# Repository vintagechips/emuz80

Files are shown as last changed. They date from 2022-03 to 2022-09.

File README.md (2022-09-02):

# emuz80
The computer with only Z80 and PIC18F47Q43<br>
<br>
The required clock frequency for the Z80 is as follows<br>
emuz80_pic.hex 2.5MHz<br>
emuz80_pic_kuma.hex 2.5MHz<br>
emuz80_pic_hlide.hex 4.6MHz<br>
emuz80_pic_yyhayami.hex 4.3MHz<br>
emuz80_pic_gazelle.hex 6MHz PIC must be replaced with PIC18F47Q84<br>
<br>
Hardware information can be found here. It is written in Japanese.<br>
https://vintagechips.wordpress.com/2022/03/05/emuz80_reference/

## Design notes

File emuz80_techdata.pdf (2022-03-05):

# EMUZ80技術資料

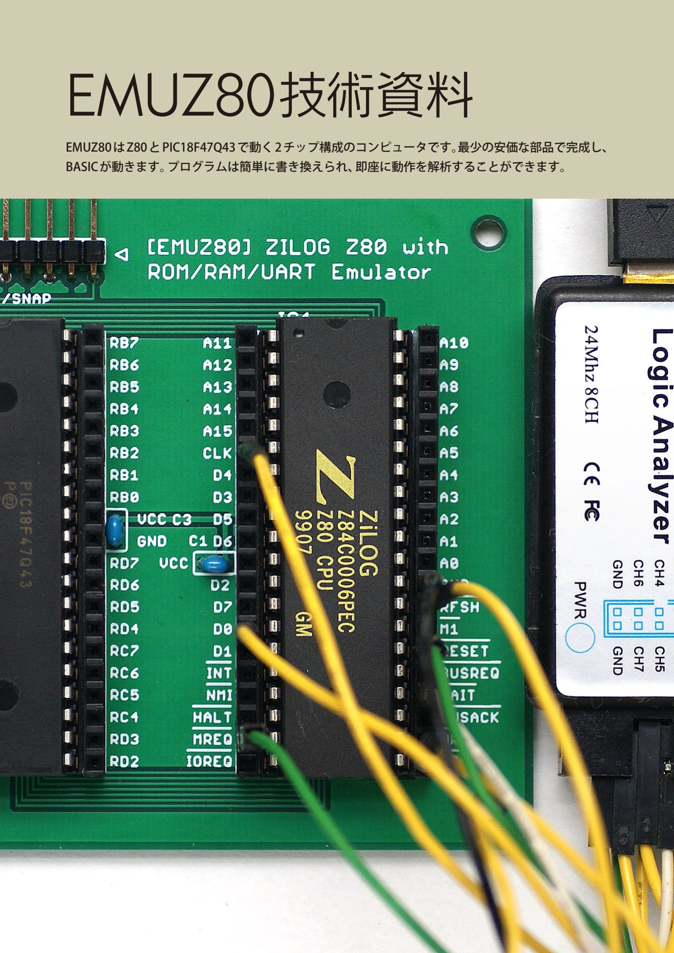
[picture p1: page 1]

EMUZ80 は Z80 と PIC18F47Q43 で動く 2 チップ構成のコンピュータです。最少の安価な部品で完成し、 BASIC が動きます。プログラムは簡単に書き換えられ、即座に動作を解析することができます。

目次

EMUZ80 の概要─3
部品表─4
回路図─5
ソルダバッドの処理─6
AC アダプタ─7
プログラムの書き込み─8
◉書き込みの準備 8
◉標準プログラムの書き込み 9
◉標準プログラムの改編 10
◉独自のプログラムの実験と解析 10
アドレスマップ─11
USB- シリアル変換ケーブル / アダプタ─12
端末ソフトの設定─13
起動の確認─14
別途配布物一覧─15

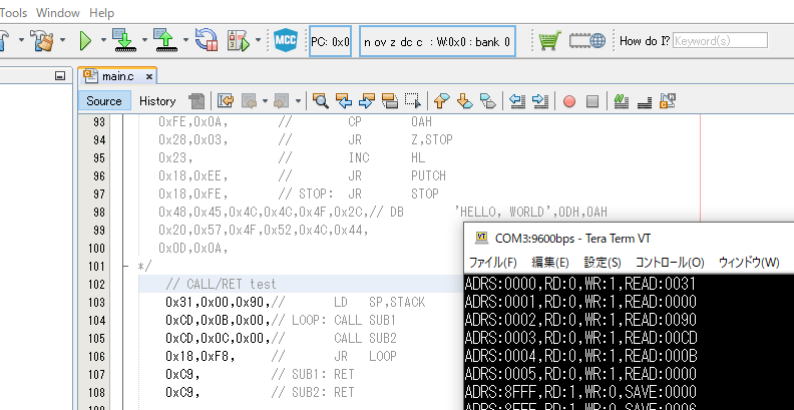
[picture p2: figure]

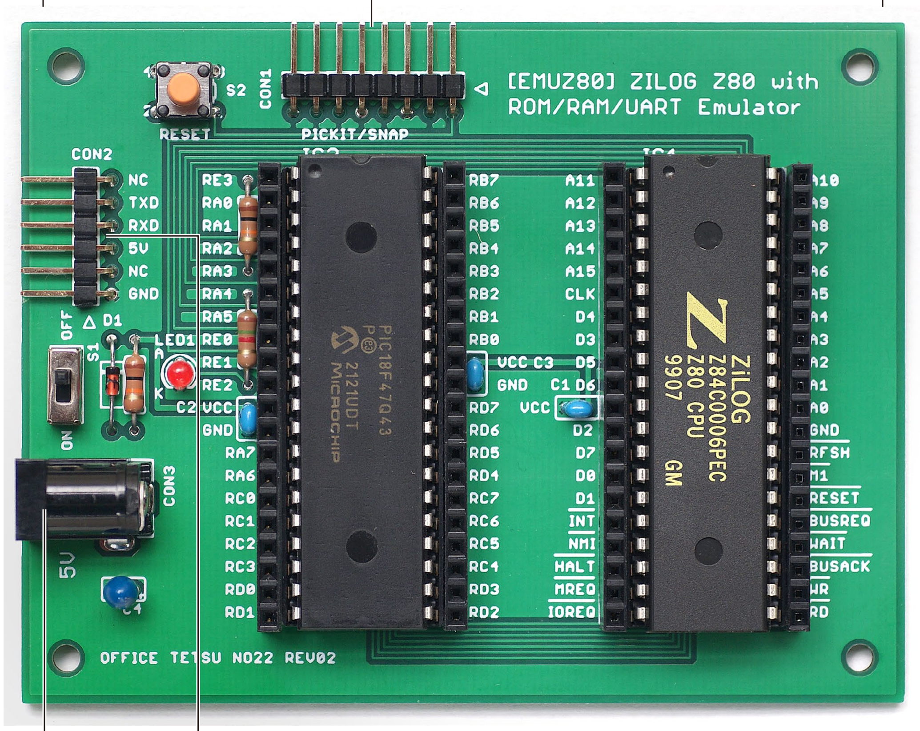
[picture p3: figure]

3

# EMUZ80の概要

EMUZ80 は部品代 1000 円で完成する Z80 のコンピュータです。ROM、RAM、シリアル（UART）は PIC18F47Q43 でエ ミュレートします。標準プログラムだと、Z80 は 2.5MHz/ 最悪 7 ウェイトで動き、BASIC を実行します。標準プログラム はいっそうの高速化を目指して改良する余地があります。ウデに自信のある人はぜひ挑戦してください。

❶本体の部品─部品表にしたがってご自身で揃え、プリント基板の部品番号が一致する位置に取り付けてください。 ❷ Snap 接続端子─ PIC18F47Q43 にプログラムを書き込むとき Snap を取り付けます。
❸ DC ジャック─電圧 5V、電流 500mA 以上、内径 2.1 mm、センタープラスの AC アダプタを接続してください。 ❸シリアル端子─ TTL-232R-5V または同等の USB- シリアル変換ケーブル / アダプタでパソコンと接続してください。
❶本体の部品 | ❷ Snap 接続端子
❸ DC ジャック | ❹シリアル端子

4

部品番号 | 型番 | 数量 | 仕様 | 販売店
IC1 | Z80 CPU | 1 | マイクロプロセッサ | オレンジピコ、若松通商
IC2 | PIC18F47Q43 | 1 | マイクロコントローラ | オレンジピコ、秋月電子通商
D1 | 1N4148 | 1 | 小信号スイッチングダイオード | オレンジピコ、秋月電子通商、若松通商
LED1 | OSRRH23133A | 1 | φ 3mm 一般 LED 各色 | オレンジピコ、秋月電子通商
R1、R2 | 10k Ω（1/4W） | 2 | カーボン抵抗 / 金属皮膜抵抗 | オレンジピコ、秋月電子通商
R3 | 1.5k Ω（1/4W） | 1 | カーボン抵抗［注 1］ | オレンジピコ、秋月電子通商
C1 ～ C3 | 0.1 μ F（50V） | 3 | 積層セラミックコンデンサ | オレンジピコ、秋月電子通商
C4 | 10 μ F（16V） | 1 | 電解 / タンタルコンデンサ | オレンジピコ、秋月電子通商
CON1、CON2 | PH-1x40RG(2) | 1 | 1 列 L 型ピンヘッダ［注 2］ | オレンジピコ、秋月電子通商
CON3 | MJ-179PH | 1 | 2.1mm φ標準 DC ジャック | オレンジピコ、秋月電子通商
S1 | SS-12D00-G5 | 1 | スライドスイッチ | オレンジピコ、秋月電子通商
S2 | DTS-6-V | 1 | 小型タクトスイッチ | オレンジピコ、秋月電子通商
─ | FH-1x20 | 4 | 20 ピン 1 列ピンソケット［注 3］ | オレンジピコ、秋月電子通商
─ | 2227-40-06 | 2 | 40 ピン IC ソケット 600mil | オレンジピコ、秋月電子通商
［注 1］R3 の抵抗値は使用する LED の輝度に応じて調整してください。
［注 2］CON1 は 8 ピン、CON2 は 6 ピンのところで折って使います。
［注 3］ご利用のジャンパー線によってはピンヘッダを取り付けてください。実験や解析をしない場合は不要です。

# 部品表

本体の部品は下に示す部品表にしたがって揃えてください。部品表の部品番号とプリント基板の部品番号を照合し、 所定の位置に取り付けると組み立て完了です。部品表には実験や解析の作業を想定した部品が含まれます。そうした 部品は、ご利用のジャンパー線などに合わせて変更し、あるいは省略することを検討してください。

## ［通販サイト］

秋月電子通商─ http://akizukidenshi.com/
オレンジピコ─ https://store.shopping.yahoo.co.jp/orangepicoshop/若松通商─ http://wakamatsu.co.jp/biz/
※ 2022 年 3 月 15 日時点の情報です。

# 回路図

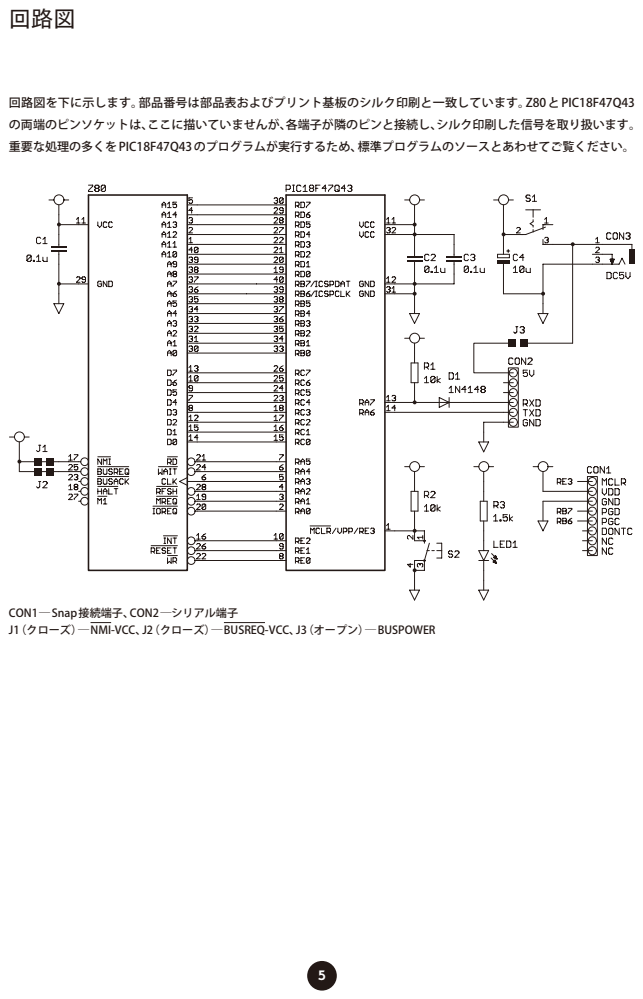
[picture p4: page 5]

回路図を下に示します。部品番号は部品表およびプリント基板のシルク印刷と一致しています。Z80 と PIC18F47Q43
の両端のピンソケットは、ここに描いていませんが、各端子が隣のピンと接続し、シルク印刷した信号を取り扱います。
重要な処理の多くを PIC18F47Q43 のプログラムが実行するため、標準プログラムのソースとあわせてご覧ください。

CON1 ─ Snap 接続端子、CON2 ─シリアル端子
J1（クローズ）─NMI-VCC、J2（クローズ）─BUSREQ-VCC、J3（オープン）─ BUSPOWER

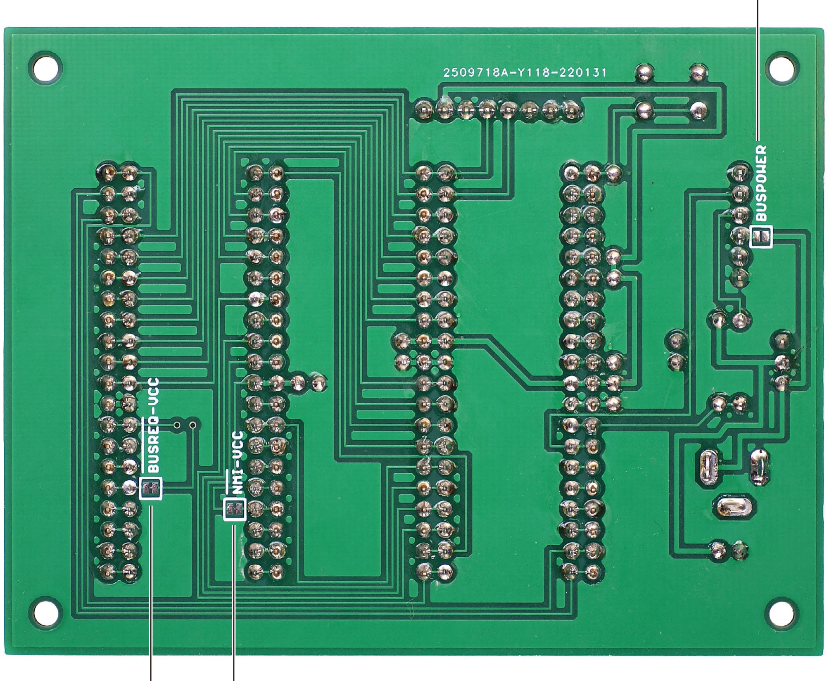
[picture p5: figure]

6

# ソルダバッドの処理

プリント基板のハンダ面に 3 か所のソルダバッドがあります。これらは原則として何もしないでください。J1 と J2 は 不使用端子を無効に固定しています。J3 は電源を USB のバスパワーからとるときクローズしますが、その場合、多く の USB- シリアル変換アダプタは電源スイッチを入れた瞬間にリセットします（TTL-232R-5V は正常に動作します）。

J3（オープン）─ BUSPOWER

J2（クローズ）─BUSREQ-VCC

J1（クローズ）─NMI-VCC

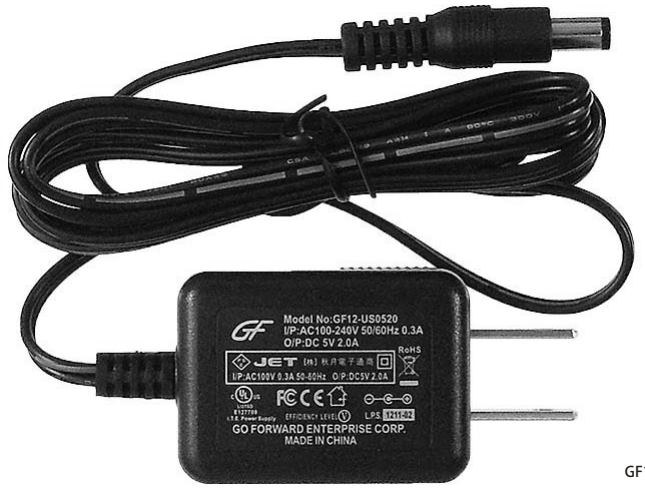
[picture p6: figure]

7

# ACアダプタ

電源は原則として AC アダプタからとります。電圧 5V、電流 500mA 以上、内径 2.1 mm、センタープラスの AC アダプタ を DC ジャックに接続してください。粗悪な製品は通電時に一瞬、電圧が 5V を超えて回路を壊す恐れがありますから、 信頼のおける製品を使ってください。EMUZ80 は秋月電子通商で販売している GF12-US0520 で動作確認しています。

GF12-US0520

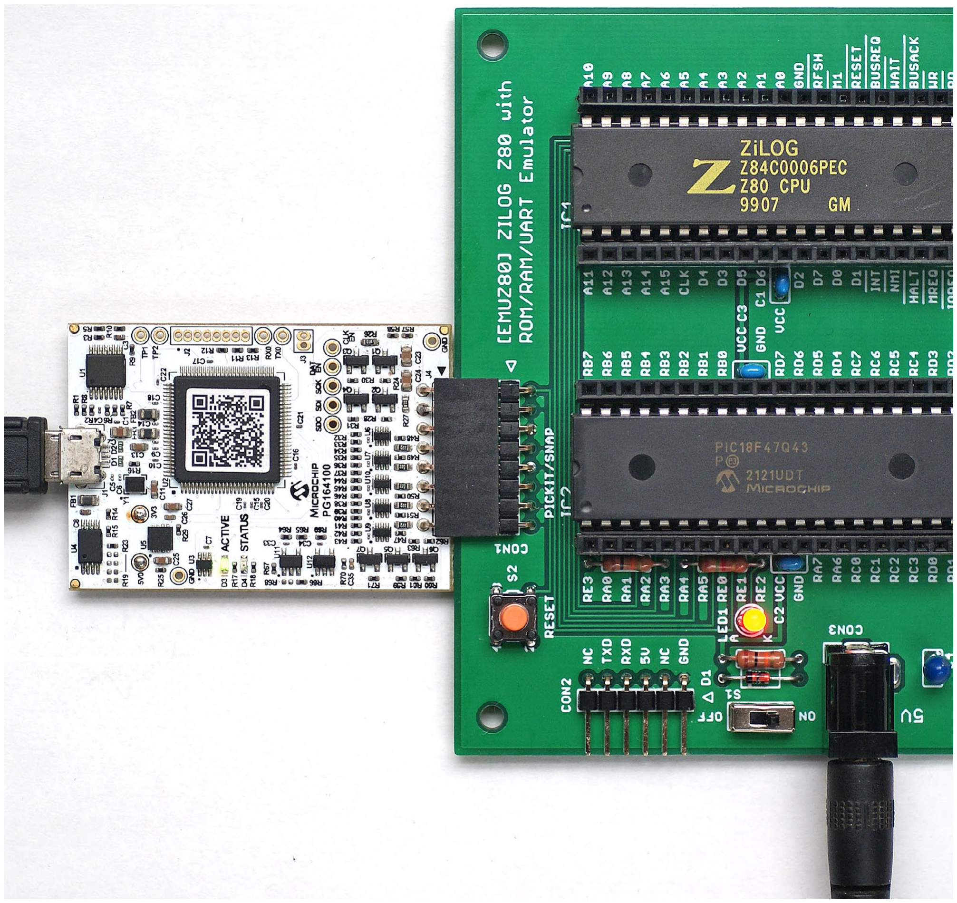
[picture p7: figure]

8

# プログラムの書き込み

PIC18F47Q43 に標準プログラムを書き込むと Z80 が BASIC を実行します。また、標準プログラムを改編して高速化を 図ったり、配列 rom[] に独自のプログラムを置いて Z80 の動作を検証したりすることができます。これらの作業のもっ とも簡単な手順を以降に示します。

◉書き込みの準備
PIC18F47Q43 の書き込みには Snap を使います。次のとおりパソコン→ Snap → EMUZ80 を接続してください。 ❶ EMUZ80 を組み立ててPIC18F47Q43 を取り付けます。Z80 が取り付けてあっても大丈夫です。
❷ CON1 に Snap を取り付けます。Snap とプリント基板は▽の位置を一致させてください。
❸ Snap のケーブルをパソコンの USB ポートに接続します。
❹ EMUZ80 の電源を入れます。

※ PICkit で書き込む場合は CON1 の▽側 6 ピンを使います。ただし、PICkit では書き込みテストをしていません。

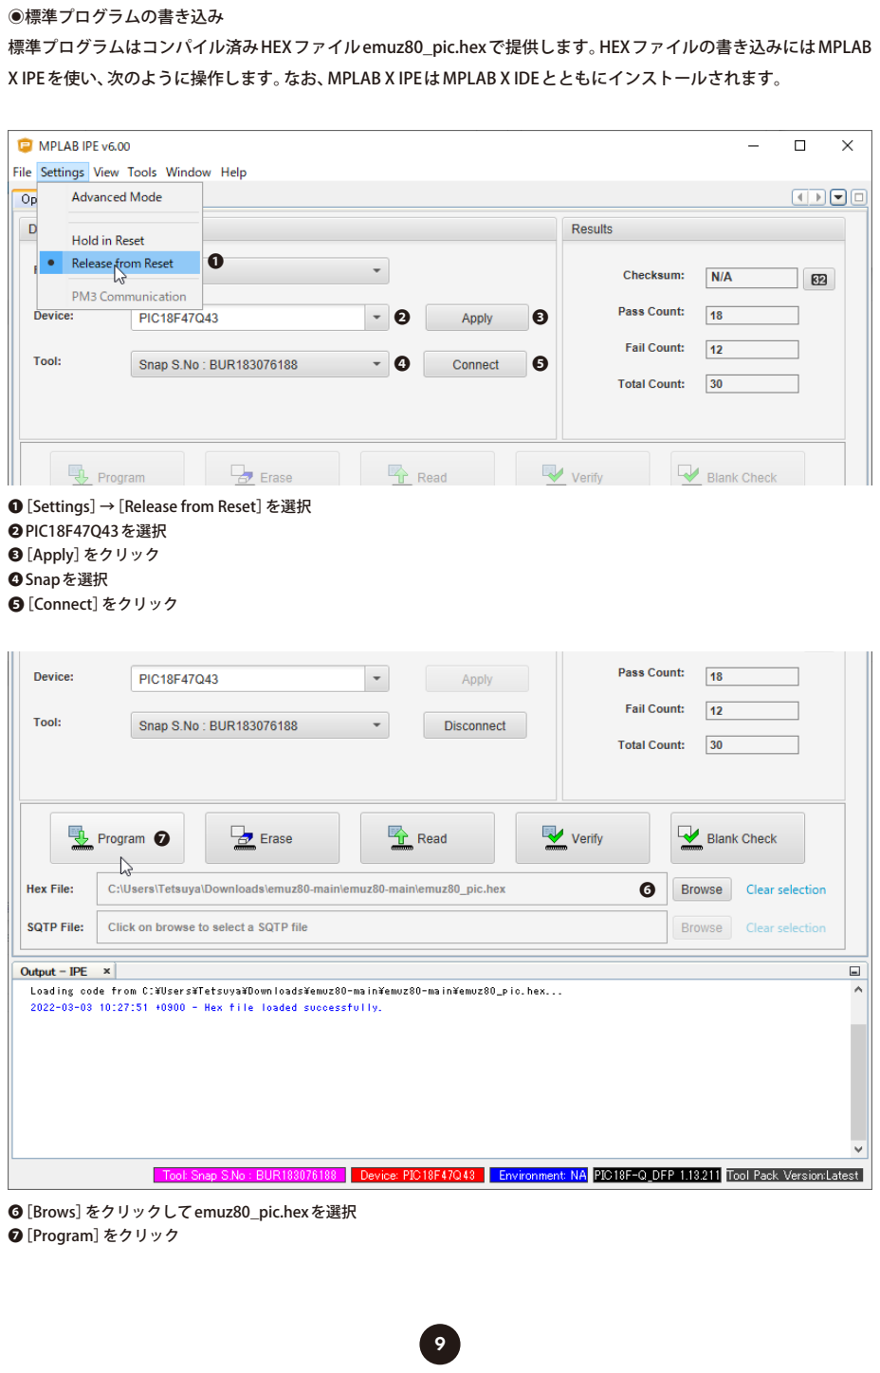
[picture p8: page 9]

9

◉標準プログラムの書き込み
標準プログラムはコンパイル済み HEX ファイル emuz80_pic.hex で提供します。HEX ファイルの書き込みには MPLAB X IPE を使い、次のように操作します。なお、MPLAB X IPE は MPLAB X IDE とともにインストールされます。

❶［Settings］→［Release from Reset］を選択 ❷ PIC18F47Q43 を選択
❸［Apply］をクリック
❹ Snap を選択
❺［Connect］をクリック

❶

❷

❹ | ❺

❻［Brows］をクリックして emuz80_pic.hex を選択 ❼［Program］をクリック

❼

❻

❸

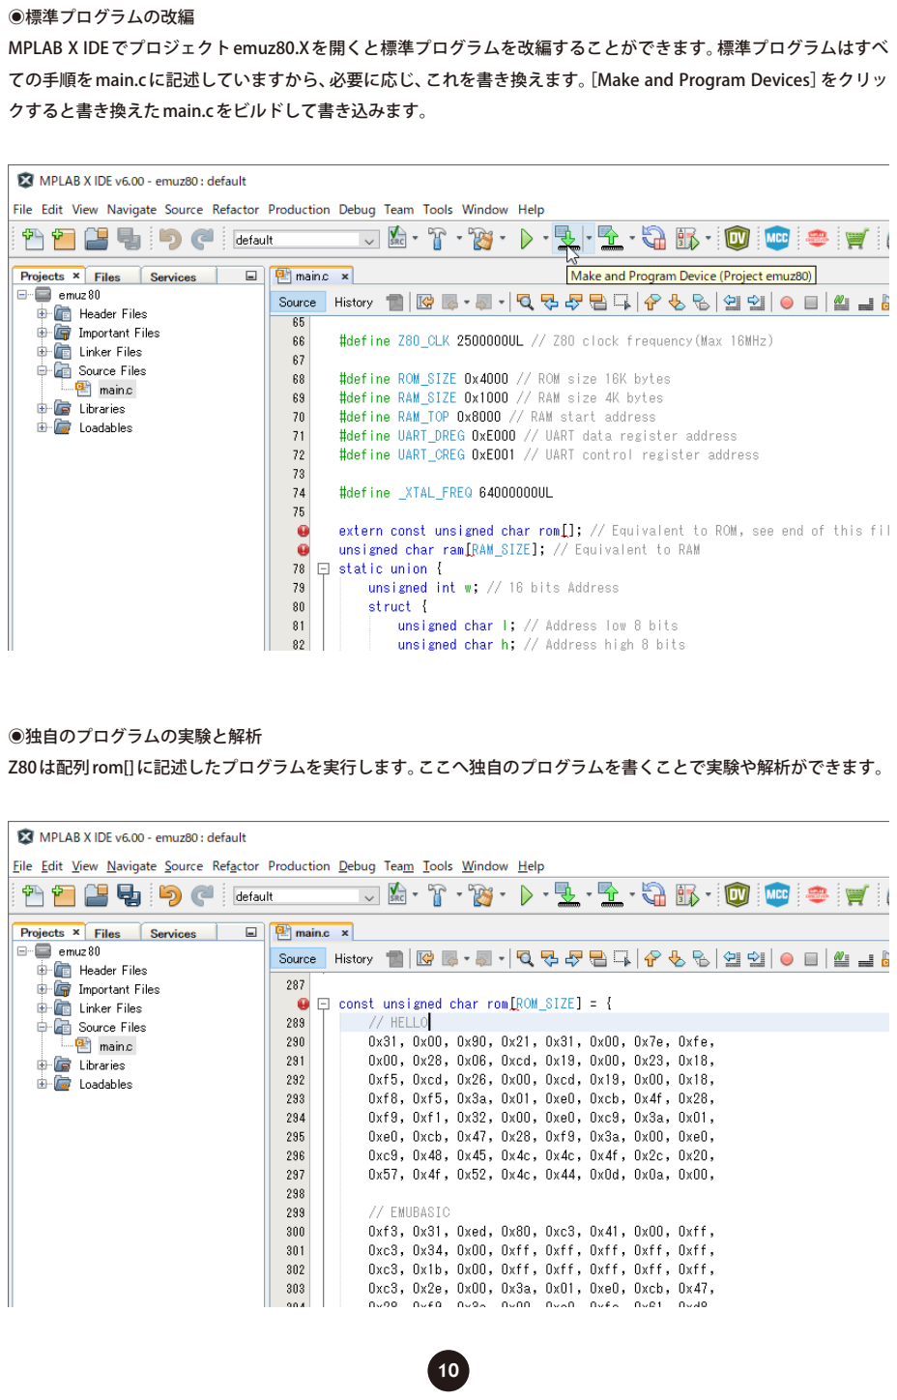
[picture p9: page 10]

10

◉標準プログラムの改編
MPLAB X IDE でプロジェクト emuz80.X を開くと標準プログラムを改編することができます。標準プログラムはすべ ての手順を main.c に記述していますから、必要に応じ、これを書き換えます。［Make and Program Devices］をクリッ クすると書き換えた main.c をビルドして書き込みます。

◉独自のプログラムの実験と解析
Z80 は配列 rom[] に記述したプログラムを実行します。ここへ独自のプログラムを書くことで実験や解析ができます。

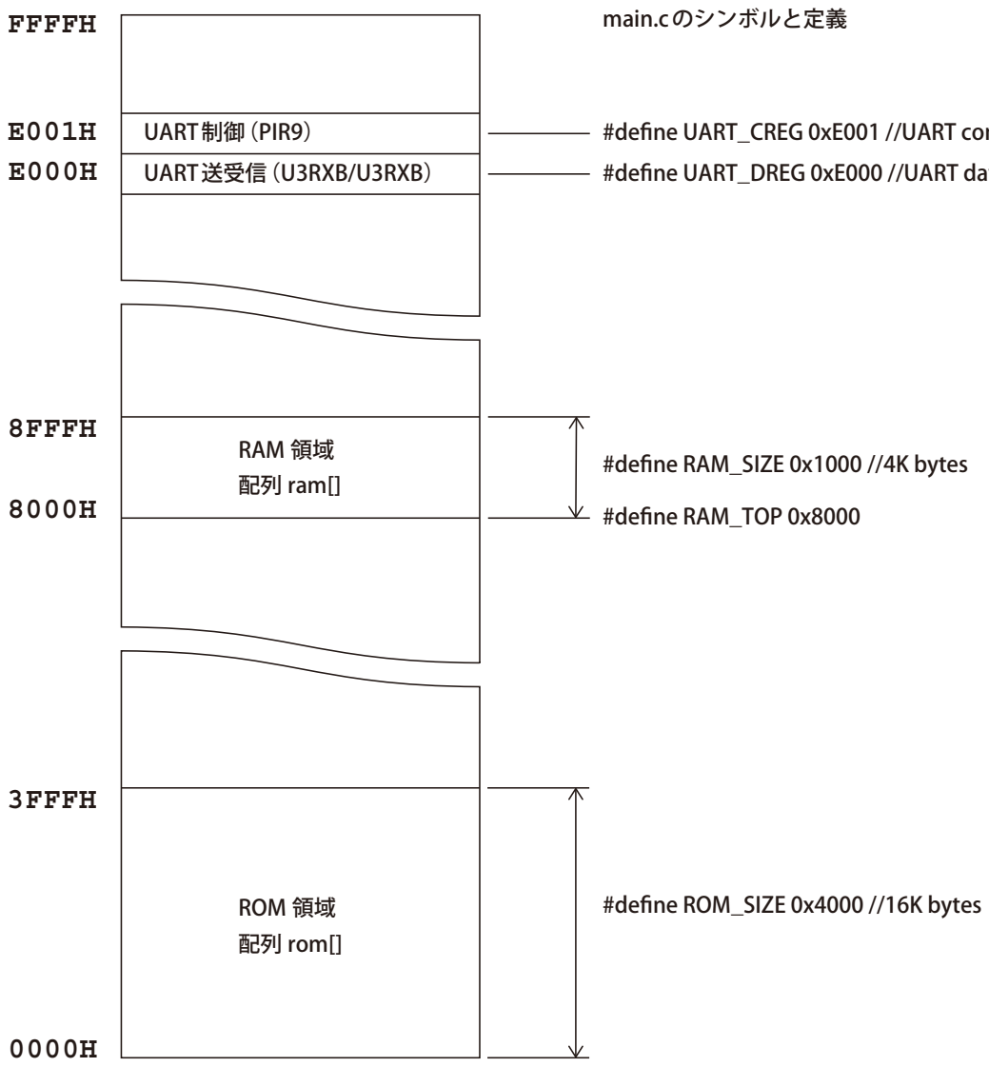
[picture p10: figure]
8FFFH; 3FFFH; ROM 領域 配列 rom[]; FFFFH; UART制御（PIR9）; UART送受信（U3RXB/U3RXB）; #define ROM_SIZE 0x4000 //16K bytes; RAM 領域; 配列 ram[]; #define RAM_SIZE 0x1000 //4K bytes; #define RAM_TOP 0x8000; main.cのシンボルと定義

11

# アドレスマップ

標準プログラムのアドレスマップを下に示します。メモリアドレスのみが存在し、IO アドレスはありません。ROM 領 域は先頭が 0000H、サイズは 16K バイトです。RAM 領域は先頭が 8000H、サイズは 4K バイトです。UART は E000H と E001H に割り当ててあり、Z80 はこのアドレスで PIC18F47Q43 のレジスタを読み書きすることになります。

#define UART_CREG 0xE001 //UART control register #define UART_DREG 0xE000 //UART data register

# USB-シリアル変換ケーブル /アダプタ

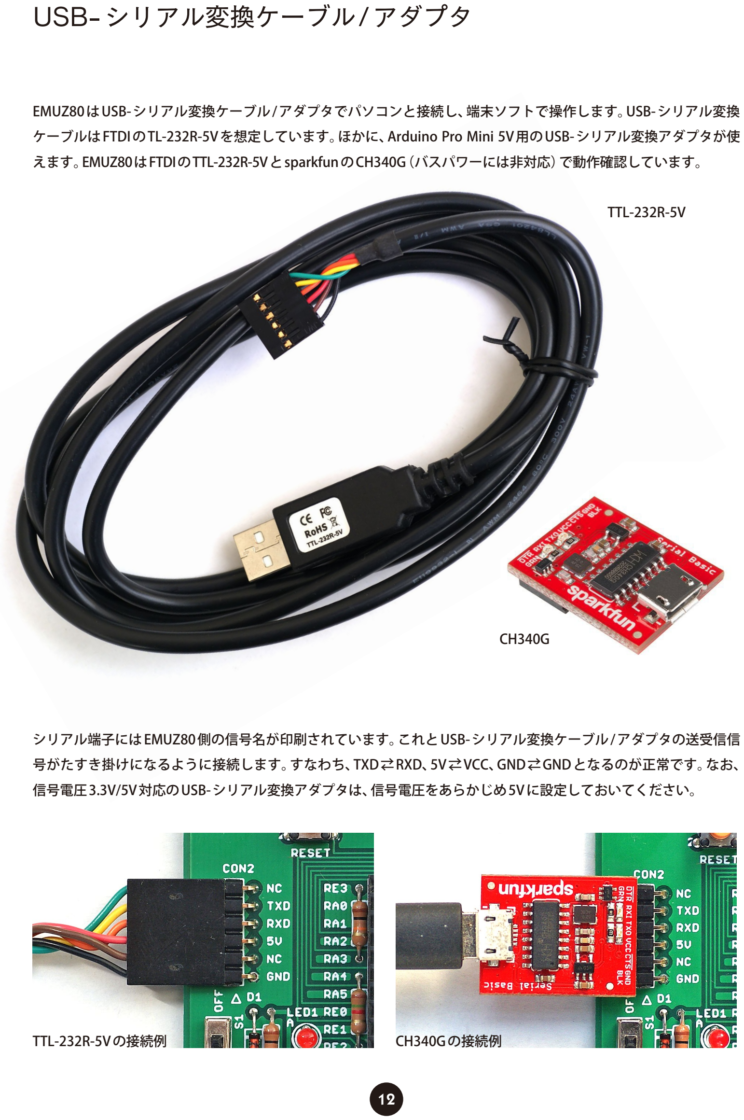
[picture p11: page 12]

12

EMUZ80 は USB- シリアル変換ケーブル / アダプタでパソコンと接続し、端末ソフトで操作します。USB- シリアル変換 ケーブルは FTDI の TL-232R-5V を想定しています。ほかに、Arduino Pro Mini 5V 用の USB- シリアル変換アダプタが使 えます。EMUZ80はFTDIのTTL-232R-5Vとsparkfun の CH340G（バスパワーには非対応）で動作確認しています。

TTL-232R-5V の接続例 | CH340G の接続例

TTL-232R-5V

シリアル端子には EMUZ80 側の信号名が印刷されています。これと USB- シリアル変換ケーブル / アダプタの送受信信 号がたすき掛けになるように接続します。すなわち、TXD ⇄ RXD、5V ⇄ VCC、GND ⇄ GND となるのが正常です。なお、 信号電圧 3.3V/5V 対応の USB- シリアル変換アダプタは、信号電圧をあらかじめ 5V に設定しておいてください。

CH340G

# 端末ソフトの設定

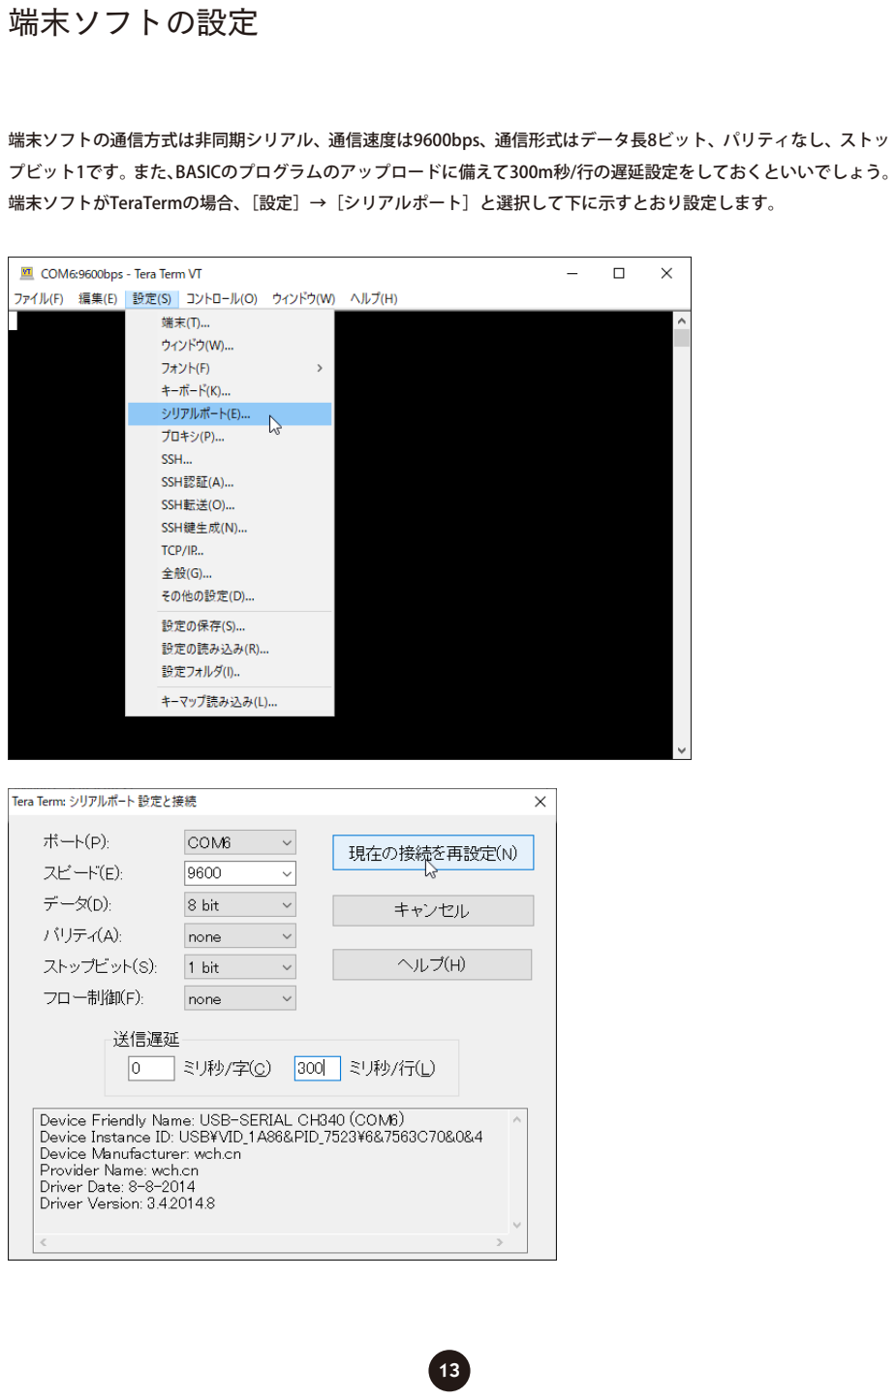
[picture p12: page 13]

13

端末ソフトの通信方式は非同期シリアル、通信速度は9600bps、通信形式はデータ長8ビット、パリティなし、ストッ プビット1です。また、BASICのプログラムのアップロードに備えて300m秒/行の遅延設定をしておくといいでしょう。 端末ソフトがTeraTermの場合、［設定］→［シリアルポート］と選択して下に示すとおり設定します。

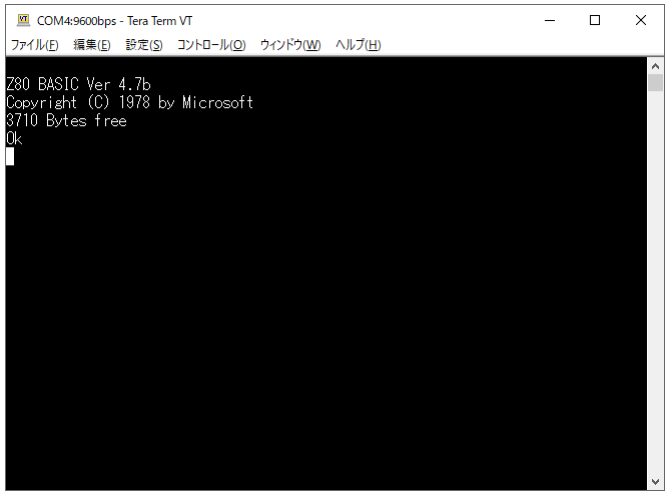
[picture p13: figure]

14

EMUZ80をパソコンと接続し、端末ソフトを開き、電源を入れると、BASICの起動メッセージが表示されます。この 時点で、部品の取り付けかたに間違いがなく、プログラムのUARTとROMも正しく動作していることがわかります。 また、空き容量が3710バイトと表示されていれば、RAMも正しく動作しています。これでEMUZ80は完成です。

# 起動の確認

BASICがASCIIART.BASの実行を完了する時間はPIC18F47Q43のプログラムの速度を測る目安になります。標準プログ ラムは23分23秒です。PIC18F47Q43のプログラムの改良を試み、BASICがこれより早くASCIIART.BASの実行を完了 したら、それは成功したといえます。なお、各種コンピュータの実測値がこちらのサイトにまとめられています。

ASCIIART( マンデルブロ集合 ) ベンチマーク─ http://haserin09.la.coocan.jp/asciiart.html

15

# 別途配布物一覧

Github のリポジトリで関連のファイルを提供しています。Github および git に不案内な人は次の URL を開き、［Code］ ボタンから［Downloard ZIP］を選択してダウンロードするのが簡単です。
◉ Github リポジトリ─ https://github.com/vintagechips/emuz80

◉ファイルリスト
README.md ─ EMUZ80 のごく簡単な説明
emuz80_pic.hex ─標準プログラム→ PIC18F47Q43 に書き込んでください emuz80_techdata.pdf ─この文書
ASCIIART.BAS ─ BASIC で実行可能なマンデルブロ集合プログラム（よくベンチマークで使われます） emuz80.X フォルダ─標準プログラムの MPLAB X IDE プロジェクト
examples フォルダ─ EMUZ80 で実行可能な Z80 コード
→ *.txt の記述を配列 rom[] の先頭に挿入し、再ビルドし、PIC18F47Q43 に書き込んでください ・HELLO フォルダ─ HELLO, WORLD とエコーバックのテスト用
・CALLRET フォルダ─ ROM、RAM、UART のテスト用→動作はロジックアナライザなどで観測してください ・EMUBASIC フォルダ─標準プログラムの配列 rom[] に書き込まれている BASIC
Eagle416 フォルダ─ Eagle v4.16 が生成したファイル

※標準プログラムより高速なプログラムがここへ追加される場合があります。

EMUZ80 技術資料
2022 年 3 月 15 日 初版発行
著者─鈴木哲哉
Copyright © 2022 Tetsuya Suzuki CC BY-NC-SA 3.0

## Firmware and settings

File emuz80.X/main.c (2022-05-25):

/*
  PIC18F47Q43 ROM RAM and UART emulation firmware
  This single source file contains all code

  Target: EMUZ80 - The computer with only Z80 and PIC18F47Q43
  Compiler: MPLAB XC8 v2.36
  Written by Tetsuya Suzuki
*/

// CONFIG1
#pragma config FEXTOSC = OFF    // External Oscillator Selection (Oscillator not enabled)
#pragma config RSTOSC = HFINTOSC_64MHZ// Reset Oscillator Selection (HFINTOSC with HFFRQ = 64 MHz and CDIV = 1:1)

// CONFIG2
#pragma config CLKOUTEN = OFF   // Clock out Enable bit (CLKOUT function is disabled)
#pragma config PR1WAY = ON      // PRLOCKED One-Way Set Enable bit (PRLOCKED bit can be cleared and set only once)
#pragma config CSWEN = ON       // Clock Switch Enable bit (Writing to NOSC and NDIV is allowed)
#pragma config FCMEN = ON       // Fail-Safe Clock Monitor Enable bit (Fail-Safe Clock Monitor enabled)

// CONFIG3
#pragma config MCLRE = EXTMCLR  // MCLR Enable bit (If LVP = 0, MCLR pin is MCLR; If LVP = 1, RE3 pin function is MCLR )
#pragma config PWRTS = PWRT_OFF // Power-up timer selection bits (PWRT is disabled)
#pragma config MVECEN = ON      // Multi-vector enable bit (Multi-vector enabled, Vector table used for interrupts)
#pragma config IVT1WAY = ON     // IVTLOCK bit One-way set enable bit (IVTLOCKED bit can be cleared and set only once)
#pragma config LPBOREN = OFF    // Low Power BOR Enable bit (Low-Power BOR disabled)
#pragma config BOREN = SBORDIS  // Brown-out Reset Enable bits (Brown-out Reset enabled , SBOREN bit is ignored)

// CONFIG4
#pragma config BORV = VBOR_1P9  // Brown-out Reset Voltage Selection bits (Brown-out Reset Voltage (VBOR) set to 1.9V)
#pragma config ZCD = OFF        // ZCD Disable bit (ZCD module is disabled. ZCD can be enabled by setting the ZCDSEN bit of ZCDCON)
#pragma config PPS1WAY = OFF    // PPSLOCK bit One-Way Set Enable bit (PPSLOCKED bit can be set and cleared repeatedly (subject to the unlock sequence))
#pragma config STVREN = ON      // Stack Full/Underflow Reset Enable bit (Stack full/underflow will cause Reset)
#pragma config LVP = ON         // Low Voltage Programming Enable bit (Low voltage programming enabled. MCLR/VPP pin function is MCLR. MCLRE configuration bit is ignored)
#pragma config XINST = OFF      // Extended Instruction Set Enable bit (Extended Instruction Set and Indexed Addressing Mode disabled)

// CONFIG5
#pragma config WDTCPS = WDTCPS_31// WDT Period selection bits (Divider ratio 1:65536; software control of WDTPS)
#pragma config WDTE = OFF       // WDT operating mode (WDT Disabled; SWDTEN is ignored)

// CONFIG6
#pragma config WDTCWS = WDTCWS_7// WDT Window Select bits (window always open (100%); software control; keyed access not required)
#pragma config WDTCCS = SC      // WDT input clock selector (Software Control)

// CONFIG7
#pragma config BBSIZE = BBSIZE_512// Boot Block Size selection bits (Boot Block size is 512 words)
#pragma config BBEN = OFF       // Boot Block enable bit (Boot block disabled)
#pragma config SAFEN = OFF      // Storage Area Flash enable bit (SAF disabled)
#pragma config DEBUG = OFF      // Background Debugger (Background Debugger disabled)

// CONFIG8
#pragma config WRTB = OFF       // Boot Block Write Protection bit (Boot Block not Write protected)
#pragma config WRTC = OFF       // Configuration Register Write Protection bit (Configuration registers not Write protected)
#pragma config WRTD = OFF       // Data EEPROM Write Protection bit (Data EEPROM not Write protected)
#pragma config WRTSAF = OFF     // SAF Write protection bit (SAF not Write Protected)
#pragma config WRTAPP = OFF     // Application Block write protection bit (Application Block not write protected)

// CONFIG10
#pragma config CP = OFF         // PFM and Data EEPROM Code Protection bit (PFM and Data EEPROM code protection disabled)

// #pragma config statements should precede project file includes.
// Use project enums instead of #define for ON and OFF.

#include <xc.h>
#include <stdio.h>

#define Z80_CLK 2500000UL // Z80 clock frequency(Max 16MHz)

#define ROM_SIZE 0x4000 //16K bytes
#define RAM_SIZE 0x1000 //4K bytes
#define RAM_TOP 0x8000 //RAM top address
#define RAM_END RAM_TOP+RAM_SIZE
#define UART_DREG 0xE000 //Data REG
#define UART_CREG 0xE001 //Control REG

#define _XTAL_FREQ 64000000UL

//Z80 ROM equivalent, see end of this file
extern const unsigned char rom[];

//Z80 RAM equivalent
unsigned char ram[RAM_SIZE];

//Address Bus
union {
    unsigned int w; //16 bits Address
    struct {
        unsigned char l; //Address low
        unsigned char h; //Address high
    };
} ab;
    
/*
// UART3 Transmit
void putch(char c) {
    while(!U3TXIF); // Wait or Tx interrupt flag set
    U3TXB = c; // Write data
}

// UART3 Recive
char getch(void) {
    while(!U3RXIF); // Wait for Rx interrupt flag set
    return U3RXB; // Read data
}
*/

// Never called, logically
void __interrupt(irq(default),base(8)) Default_ISR(){}

// Called at WAIT falling edge(Immediately after Z80 MREQ falling)
void __interrupt(irq(CLC1),base(8)) CLC_ISR(){
    CLC1IF = 0; // Clear interrupt flag
    
    ab.h = PORTD; // Read address high
    ab.l = PORTB; // Read address low
    
  //Z80 memory write cycle
  if(RA5) {
    if((ab.w >= RAM_TOP) && (ab.w < RAM_END)) // RAM area
      ram[ab.w - RAM_TOP] = PORTC; // Write into RAM
    else if(ab.w == UART_DREG) // U3TXB
      U3TXB = PORTC; // Write into  U3TXB
    //Release wait (D-FF reset)
    G3POL = 1;
    G3POL = 0;
    return;
  }

  //Z80 memory read cycle
  TRISC = 0x00; // Set data bus as output
  if(ab.w < ROM_SIZE) // ROM area
    LATC = rom[ab.w]; // Out ROM data
  else if((ab.w >= RAM_TOP) && (ab.w < RAM_END)) // RAM area
    LATC = ram[ab.w - RAM_TOP]; // Out RAM data
  else if(ab.w == UART_CREG) // PIR9
    LATC = PIR9; // Out PIR9
  else if(ab.w == UART_DREG) //U3RXB
    LATC = U3RXB; // Out U3RXB
  else //Empty
    LATC = 0xff; //Invalid data
  //Release wait (D-FF reset)
  G3POL = 1;
  G3POL = 0;

  //Post processing
  while(!RA1);
  TRISC = 0xff; //Set as input
}

// main routine
void main(void) {
    // System initialize
    OSCFRQ = 0x08; // 64MHz internal OSC

    // Address bus A15-A8 pin
    ANSELD = 0x00; // Disable analog function
    WPUD = 0xff; // Week pull up
    TRISD = 0xff; // Set as input

    // Address bus A7-A0 pin
    ANSELB = 0x00; // Disable analog function
    WPUB = 0xff; // Week pull up
    TRISB = 0xff; // Set as input

    // Data bus D7-D0 pin
    ANSELC = 0x00; // Disable analog function
    WPUC = 0xff; // Week pull up
    TRISC = 0xff; // Set as input(default)

    // WR input pin
    ANSELE0 = 0; // Disable analog function
    WPUE0 = 1; // Week pull up
    TRISE0 = 1; // Set as input

    // RESET output pin
    ANSELE1 = 0; // Disable analog function
    LATE1 = 0; // Reset
    TRISE1 = 0; // Set as output

    // INT output pin
    ANSELE2 = 0; // Disable analog function
    LATE2 = 1; // No interrupt request
    TRISE2 = 0; // Set as output

    // IOREQ input pin
    ANSELA0 = 0; // Disable analog function
    WPUA0 = 1; // Week pull up
    TRISA0 = 1; // Set as input

    // RD(RA5)  input pin
    ANSELA5 = 0; // Disable analog function
    WPUA5 = 1; // Week pull up
    TRISA5 = 1; // Set as intput

    // Z80 clock(RA3) by NCO FDC mode
    RA3PPS = 0x3f; // RA3 asign NCO1
    ANSELA3 = 0; // Disable analog function
    TRISA3 = 0; // NCO output pin
    NCO1INC = Z80_CLK * 2 / 61;
    NCO1CLK = 0x00; // Clock source Fosc
    NCO1PFM = 0;  // FDC mode
    NCO1OUT = 1;  // NCO output enable
    NCO1EN = 1;   // NCO enable

    // UART3 initialize
    U3BRG = 416; // 9600bps @ 64MHz
    U3RXEN = 1; // Receiver enable
    U3TXEN = 1; // Transmitter enable

    // UART3 Receiver
    ANSELA7 = 0; // Disable analog function
    TRISA7 = 1; // RX set as input
    U3RXPPS = 0x07; //RA7->UART3:RX3;

    // UART3 Transmitter
    ANSELA6 = 0; // Disable analog function
    LATA6 = 1; // Default level
    TRISA6 = 0; // TX set as output
    RA6PPS = 0x26;  //RA6->UART3:TX3;

    U3ON = 1; // Serial port enable
    
    // MREQ(RA1) CLC input pin
    ANSELA1 = 0; // Disable analog function
    WPUA1 = 1; // Week pull up
    TRISA1 = 1; // Set as input
    CLCIN0PPS = 0x1; //RA1->CLC1:CLCIN0;

    // RFSH(RA2) CLC input pin
    ANSELA2 = 0; // Disable analog function
    WPUA2 = 1; // Week pull up
    TRISA2 = 1; // Set as input
    CLCIN1PPS = 0x2; //RA2->CLC1:CLCIN1;

    // WAIT(RA4) CLC output pin
    ANSELA4 = 0; // Disable analog function
    LATA4 = 1; // Default level
    TRISA4 = 0; // Set as output
    RA4PPS = 0x01;  //RA4->CLC1:CLC1;

    // CLC logic configuration
    CLCSELECT = 0x0; // Use only 1 CLC instance  
    CLCnPOL = 0x82; // LCG2POL inverted, LCPOL inverted

    // CLC data inputs select
    CLCnSEL0 = 0; // D-FF CLK assign CLCIN0PPS(RA1)
    CLCnSEL1 = 1; // D-FF D assign CLCIN1PPS(RA2) 
    CLCnSEL2 = 127; // D-FF S assign none
    CLCnSEL3 = 127; // D-FF R assign none

    // CLCn gates logic select
    CLCnGLS0 = 0x1; // Connect LCG1D1N 
    CLCnGLS1 = 0x4; // Connect LCG2D2N
    CLCnGLS2 = 0x0; // Connect none
    CLCnGLS3 = 0x0; // Connect none

    CLCDATA = 0x0; // Clear all CLC outs
    CLCnCON = 0x8c; // Select D-FF, falling edge inturrupt

    // Unlock IVT
    IVTLOCK = 0x55;
    IVTLOCK = 0xAA;
    IVTLOCKbits.IVTLOCKED = 0x00;

    // Default IVT base address
    IVTBASE = 0x000008;

    // Lock IVT
    IVTLOCK = 0x55;
    IVTLOCK = 0xAA;
    IVTLOCKbits.IVTLOCKED = 0x01;

    // CLC VI enable
    CLC1IF = 0; // Clear the CLC interrupt flag
    CLC1IE = 1; // Enabling CLC1 interrupt

    // Z80 start
    GIE = 1; // Global interrupt enable
    LATE1 = 1; // Release reset

    while(1); // All things come to those who wait
}

const unsigned char rom[ROM_SIZE] = {
/*
    // HELLO
	0x31, 0x00, 0x90, 0x21, 0x31, 0x00, 0x7e, 0xfe,
	0x00, 0x28, 0x06, 0xcd, 0x19, 0x00, 0x23, 0x18,
	0xf5, 0xcd, 0x26, 0x00, 0xcd, 0x19, 0x00, 0x18,
	0xf8, 0xf5, 0x3a, 0x01, 0xe0, 0xcb, 0x4f, 0x28,
	0xf9, 0xf1, 0x32, 0x00, 0xe0, 0xc9, 0x3a, 0x01,
	0xe0, 0xcb, 0x47, 0x28, 0xf9, 0x3a, 0x00, 0xe0,
	0xc9, 0x48, 0x45, 0x4c, 0x4c, 0x4f, 0x2c, 0x20,
	0x57, 0x4f, 0x52, 0x4c, 0x44, 0x0d, 0x0a, 0x00,
*/
    // EMUBASIC
	0xf3, 0x31, 0xed, 0x80, 0xc3, 0x41, 0x00, 0xff,
	0xc3, 0x34, 0x00, 0xff, 0xff, 0xff, 0xff, 0xff,
	0xc3, 0x1b, 0x00, 0xff, 0xff, 0xff, 0xff, 0xff,
	0xc3, 0x2e, 0x00, 0x3a, 0x01, 0xe0, 0xcb, 0x47,
	0x28, 0xf9, 0x3a, 0x00, 0xe0, 0xfe, 0x61, 0xd8,
	0xfe, 0x7b, 0xd0, 0xe6, 0xdf, 0xc9, 0x3a, 0x01,
	0xe0, 0xcb, 0x47, 0xc9, 0xf5, 0x3a, 0x01, 0xe0,
	0xcb, 0x4f, 0x28, 0xf9, 0xf1, 0x32, 0x00, 0xe0,
	0xc9, 0xc3, 0x44, 0x00, 0xc3, 0x4a, 0x00, 0xc3,
	0xbf, 0x00, 0xc3, 0x51, 0x00, 0x02, 0x09, 0x78,
	0x10, 0x21, 0x45, 0x80, 0xf9, 0xc3, 0x93, 0x1c,
	0x11, 0x29, 0x03, 0x06, 0x63, 0x21, 0x45, 0x80,
	0x1a, 0x77, 0x23, 0x13, 0x05, 0xc2, 0x60, 0x00,
	0xf9, 0xcd, 0x2a, 0x05, 0xcd, 0xf8, 0x0a, 0x32,
	0xef, 0x80, 0x32, 0x3e, 0x81, 0x21, 0xa2, 0x81,
	0x23, 0x7c, 0xb5, 0xca, 0x87, 0x00, 0x7e, 0x47,
	0x2f, 0x77, 0xbe, 0x70, 0xca, 0x78, 0x00, 0x2b,
	0x11, 0xa1, 0x81, 0xcd, 0xc0, 0x06, 0xda, 0xc8,
	0x00, 0x11, 0xce, 0xff, 0x22, 0xf4, 0x80, 0x19,
	0x22, 0x9f, 0x80, 0xcd, 0x05, 0x05, 0x2a, 0x9f,
	0x80, 0x11, 0xef, 0xff, 0x19, 0x11, 0x3e, 0x81,
	0x7d, 0x93, 0x6f, 0x7c, 0x9a, 0x67, 0xe5, 0x21,
	0xe0, 0x00, 0xcd, 0x96, 0x11, 0xe1, 0xcd, 0x39,
	0x18, 0x21, 0xd1, 0x00, 0xcd, 0x96, 0x11, 0x31,
	0xab, 0x80, 0xcd, 0x2a, 0x05, 0xc3, 0x43, 0x04,
	0x21, 0x17, 0x01, 0xcd, 0x96, 0x11, 0xc3, 0xce,
	0x00, 0x20, 0x42, 0x79, 0x74, 0x65, 0x73, 0x20,
	0x66, 0x72, 0x65, 0x65, 0x0d, 0x0a, 0x00, 0x00,
	0x5a, 0x38, 0x30, 0x20, 0x42, 0x41, 0x53, 0x49,
	0x43, 0x20, 0x56, 0x65, 0x72, 0x20, 0x34, 0x2e,
	0x37, 0x62, 0x0d, 0x0a, 0x43, 0x6f, 0x70, 0x79,
	0x72, 0x69, 0x67, 0x68, 0x74, 0x20, 0x28, 0x43,
	0x29, 0x20, 0x31, 0x39, 0x37, 0x38, 0x20, 0x62,
	0x79, 0x20, 0x4d, 0x69, 0x63, 0x72, 0x6f, 0x73,
	0x6f, 0x66, 0x74, 0x0d, 0x0a, 0x00, 0x00, 0x4d,
	0x65, 0x6d, 0x6f, 0x72, 0x79, 0x20, 0x73, 0x69,
	0x7a, 0x65, 0x20, 0x6e, 0x6f, 0x74, 0x20, 0x65,
	0x6e, 0x6f, 0x75, 0x67, 0x68, 0x0d, 0x0a, 0x54,
	0x68, 0x65, 0x20, 0x73, 0x79, 0x73, 0x74, 0x65,
	0x6d, 0x20, 0x69, 0x73, 0x20, 0x73, 0x74, 0x6f,
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
};

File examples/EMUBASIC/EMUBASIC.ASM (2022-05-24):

;	EMUBASIC based on GRANT's BASIC
;	TARGET: EMUZ80
;	ASSEMBLER: ARCPIT XZ80.EXE
;
;	START UP ROUTINE
;	VERSION 1.0, 2022/02/15
;	WRITTEN by TETSUYA SUZUKI
;
;	MEMORY ASIGN
ROMTOP	EQU	0000H
RAMTOP	EQU	8000H
RAMSIZ	EQU	1000H
TSTACK	EQU	80EDH
;
;	UART REGISTER ADDRESS
UARTDR	EQU	0E000H	; UART DATA REGISTOR
UARTCR	EQU	0E001H	; UART CONTROL REGISTOR
;
;	RESET (RST 00H)
	ORG	ROMTOP
	DI
	LD	SP,TSTACK
	JP	SINIT
;
;	PUT 1CHAR (RST 08H)
	ORG	ROMTOP+08H
	JP	TXA
;
;	GET 1CHAR (RST 10H)
	ORG	ROMTOP+10H
	JP	RXA
;
;	KBHIT (RST 18H)
	ORG	ROMTOP+18H
	JP	KBHIT
;
;	UART -> A
RXA:	LD	A,(UARTCR)
	BIT	0,A
	JR	Z,RXA
	LD	A,(UARTDR)
	CP	'a'
	RET	C
	CP	'z'+1
	RET	NC
	AND	0DFH
	RET
;
;	CHECK RECEIVE STATUS
KBHIT:	LD	A,(UARTCR)
	BIT	0,A
	RET
;
;	A -> UART
TXA:	PUSH	AF
TXAST1:	LD	A,(UARTCR)
	BIT	1,A
	JR	Z,TXAST1
	POP	AF
	LD	(UARTDR),A
	RET
;
;
;	SYSTEM INITIALIZE
SINIT:
	JP	COLD
;
;==================================================================================
; The updates to the original BASIC within this file are copyright Grant Searle
;
; You have permission to use this for NON COMMERCIAL USE ONLY
; If you wish to use it elsewhere, please include an acknowledgement to myself.
;
; http://searle.hostei.com/grant/index.html
;
; eMail: home.micros01@btinternet.com
;
; If the above don't work, please perform an Internet search to see if I have
; updated the web page hosting service.
;
;==================================================================================
;
; NASCOM ROM BASIC Ver 4.7, (C) 1978 Microsoft
; Scanned from source published in 80-BUS NEWS from Vol 2, Issue 3
; (May-June 1983) to Vol 3, Issue 3 (May-June 1984)
; Adapted for the freeware Zilog Macro Assembler 2.10 to produce
; the original ROM code (checksum A934H). PA
;
; GENERAL EQUATES
;
CTRLC	EQU	03H		; Control "C"
CTRLG	EQU	07H		; Control "G"
BKSP	EQU	08H		; Back space
LF	EQU	0AH		; Line feed
CS	EQU	0CH		; Clear screen
CR	EQU	0DH		; Carriage return
CTRLO	EQU	0FH		; Control "O"
CTRLQ	EQU	11H		; Control "Q"
CTRLR	EQU	12H		; Control "R"
CTRLS	EQU	13H		; Control "S"
CTRLU	EQU	15H		; Control "U"
ESC	EQU	1BH		; Escape
DEL	EQU	7FH		; Delete
;
; BASIC WORK SPACE LOCATIONS
;
WRKSPC	EQU	8045H		; BASIC Work space
USR	EQU	WRKSPC+3H	; "USR (x)" jump
OUTSUB	EQU	WRKSPC+6H	; "OUT p,n"
OTPORT	EQU	WRKSPC+7H	; Port (p)
DIVSUP	EQU	WRKSPC+9H	; Division support routine
DIV1	EQU	WRKSPC+0AH	; <- Values
DIV2	EQU	WRKSPC+0EH	; <- to
DIV3	EQU	WRKSPC+12H	; <- be
DIV4	EQU	WRKSPC+15H	; <- inserted
SEED	EQU	WRKSPC+17H	; Random number seed
LSTRND	EQU	WRKSPC+3AH	; Last random number
INPSUB	EQU	WRKSPC+3EH	; #INP (x)" Routine
INPORT	EQU	WRKSPC+3FH	; PORT (x)
NULLS	EQU	WRKSPC+41H	; Number of nulls
LWIDTH	EQU	WRKSPC+42H	; Terminal width
COMMAN	EQU	WRKSPC+43H	; Width for commas
NULFLG	EQU	WRKSPC+44H	; Null after input byte flag
CTLOFG	EQU	WRKSPC+45H	; Control "O" flag
LINESC	EQU	WRKSPC+46H	; Lines counter
LINESN	EQU	WRKSPC+48H	; Lines number
CHKSUM	EQU	WRKSPC+4AH	; Array load/save check sum
NMIFLG	EQU	WRKSPC+4CH	; Flag for NMI break routine
BRKFLG	EQU	WRKSPC+4DH	; Break flag
RINPUT	EQU	WRKSPC+4EH	; Input reflection
POINT	EQU	WRKSPC+51H	; "POINT" reflection (unused)
PSET	EQU	WRKSPC+54H	; "SET"	reflection
RESET	EQU	WRKSPC+57H	; "RESET" reflection
STRSPC	EQU	WRKSPC+5AH	; Bottom of string space
LINEAT	EQU	WRKSPC+5CH	; Current line number
BASTXT	EQU	WRKSPC+5EH	; Pointer to start of program
BUFFER	EQU	WRKSPC+61H	; Input buffer
STACK	EQU	WRKSPC+66H	; Initial stack
CURPOS	EQU	WRKSPC+0ABH	; Character position on line
LCRFLG	EQU	WRKSPC+0ACH	; Locate/Create flag
TYPE	EQU	WRKSPC+0ADH	; Data type flag
DATFLG	EQU	WRKSPC+0AEH	; Literal statement flag
LSTRAM	EQU	WRKSPC+0AFH	; Last available RAM
TMSTPT	EQU	WRKSPC+0B1H	; Temporary string pointer
TMSTPL	EQU	WRKSPC+0B3H	; Temporary string pool
TMPSTR	EQU	WRKSPC+0BFH	; Temporary string
STRBOT	EQU	WRKSPC+0C3H	; Bottom of string space
CUROPR	EQU	WRKSPC+0C5H	; Current operator in EVAL
LOOPST	EQU	WRKSPC+0C7H	; First statement of loop
DATLIN	EQU	WRKSPC+0C9H	; Line of current DATA item
FORFLG	EQU	WRKSPC+0CBH	; "FOR" loop flag
LSTBIN	EQU	WRKSPC+0CCH	; Last byte entered
READFG	EQU	WRKSPC+0CDH	; Read/Input flag
BRKLIN	EQU	WRKSPC+0CEH	; Line of break
NXTOPR	EQU	WRKSPC+0D0H	; Next operator in EVAL
ERRLIN	EQU	WRKSPC+0D2H	; Line of error
CONTAD	EQU	WRKSPC+0D4H	; Where to CONTinue
PROGND	EQU	WRKSPC+0D6H	; End of program
VAREND	EQU	WRKSPC+0D8H	; End of variables
ARREND	EQU	WRKSPC+0DAH	; End of arrays
NXTDAT	EQU	WRKSPC+0DCH	; Next data item
FNRGNM	EQU	WRKSPC+0DEH	; Name of FN argument
FNARG	EQU	WRKSPC+0E0H	; FN argument value
FPREG	EQU	WRKSPC+0E4H	; Floating point register
FPEXP	EQU	FPREG+3		; Floating point exponent
SGNRES	EQU	WRKSPC+0E8H	; Sign of result
PBUFF	EQU	WRKSPC+0E9H	; Number print buffer
MULVAL	EQU	WRKSPC+0F6H	; Multiplier
PROGST	EQU	WRKSPC+0F9H	; Start of program text area
STLOOK	EQU	WRKSPC+15DH	; Start of memory test
;
; BASIC ERROR CODE VALUES
;
NF	EQU	00H		; NEXT without FOR
SN	EQU	02H		; Syntax error
RG	EQU	04H		; RETURN without GOSUB
OD	EQU	06H		; Out of DATA
FC	EQU	08H		; Function call error
OV	EQU	0AH		; Overflow
OM	EQU	0CH		; Out of memory
UL	EQU	0EH		; Undefined line number
BS	EQU	10H		; Bad subscript
RD	EQU	12H		; Re-DIMensioned array
DZ	EQU	14H		; Division by zero (/0)
ID	EQU	16H		; Illegal direct
TM	EQU	18H		; Type miss-match
OS	EQU	1AH		; Out of string space
LS	EQU	1CH		; String too long
ST	EQU	1EH		; String formula too complex
CN	EQU	20H		; Can't CONTinue
UF	EQU	22H		; UnDEFined FN function
MO	EQU	24H		; Missing operand
HX	EQU	26H		; HEX error
BN	EQU	28H		; BIN error
;
COLD:	JP	STARTB		; Jump for cold start
WARM:	JP	WARMST		; Jump for warm start
STARTB: JP	CSTART		; Jump to initialise
;
	DW	DEINT		; Get integer -32768 to 32767
	DW	ABPASS		; Return integer in AB
;
CSTART: LD	HL,WRKSPC	; Start of workspace RAM
	LD	SP,HL		; Set up a temporary stack
	JP	INITST		; Go to initialise
;
INIT:	LD	DE,INITAB	; Initialise workspace
	LD	B,INITBE-INITAB+3; Bytes to copy
	LD	HL,WRKSPC	; Into workspace RAM
COPY:	LD	A,(DE)		; Get source
	LD	(HL),A		; To destination
	INC	HL		; Next destination
	INC	DE		; Next source
	DEC	B		; Count bytes
	JP	NZ,COPY		; More to move
	LD	SP,HL		; Temporary stack
	CALL	CLREG		; Clear registers and stack
	CALL	PRCRLF		; Output CRLF
	LD	(BUFFER+72+1),A	; Mark end of buffer
	LD	(PROGST),A	; Initialise program area
MSIZE:	LD	HL,STLOOK	; Point to start of RAM
MLOOP:	INC	HL		; Next byte
	LD	A,H		; Above address FFFF ?
	OR	L
	JP	Z,SETTOP	; Yes - 64K RAM
	LD	A,(HL)		; Get contents
	LD	B,A		; Save it
	CPL			; Flip all bits
	LD	(HL),A		; Put it back
	CP	(HL)		; RAM there if same
	LD	(HL),B		; Restore old contents
	JP	Z,MLOOP		; If RAM - test next byte
;
SETTOP: DEC	HL		; Back one byte
	LD	DE,STLOOK-1	; See if enough RAM
	CALL	CPDEHL		; Compare DE with HL
	JP	C,NEMEM		; If not enough RAM
	LD	DE,0-50		; 50 Bytes string space
	LD	(LSTRAM),HL	; Save last available RAM
	ADD	HL,DE		; Allocate string space
	LD	(STRSPC),HL	; Save string space
	CALL	CLRPTR		; Clear program area
	LD	HL,(STRSPC)	; Get end of memory
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

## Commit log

2022-03-04 Eagle 4.16 generated file
    [EMUZ80R3.brd, EMUZ80R3.sch]
2022-03-04 Gerber file
2022-03-04 Eagle 4.16 generated files
    [EMUZ80R3.brd, EMUZ80R3.sch]
2022-04-12 Comment has been corrected
    [HELLO.ASM]
